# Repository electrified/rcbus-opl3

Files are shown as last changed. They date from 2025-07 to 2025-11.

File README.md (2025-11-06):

# RCBus OPL3 Sound card

An OPL3 sound card for RC2014/RCBus based computers, based on the Yamaha YMF262 and YAC512 ICs.

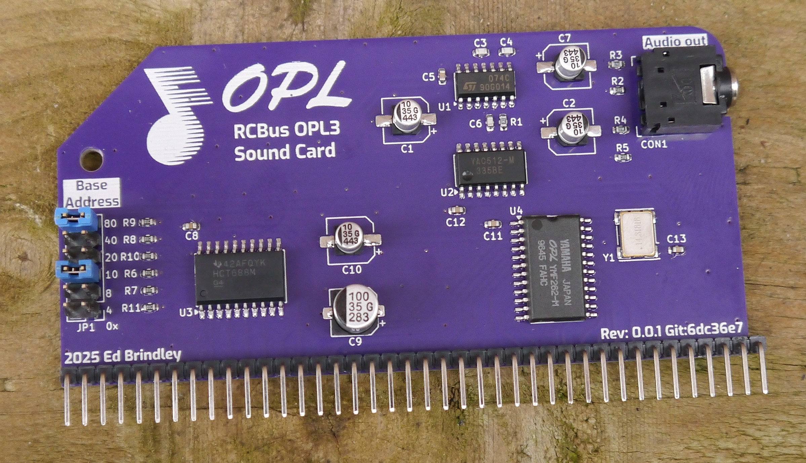
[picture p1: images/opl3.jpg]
Picture of the board


## Building the board
A site built from the sources is available https://electrified.github.io/rcbus-opl3-site. For Gerbers to get your own PCB manufactured see here, download the most appropriate zip for your PCB manufacturer: https://electrified.github.io/rcbus-opl3-site/Browse/rcbus-opl3-navigate_PCB_fabrication_gerber.html

### BOM
The BOM for the board is available here https://electrified.github.io/rcbus-opl3-site/Browse/rcbus-opl3-navigate_Schematic_BoM.html. The CSV version can be loaded into sites that have BOM upload functionality.

## Configuration
The base address the card is available at is configured with JP1 - the default setting which VGMPLAY expects is **0x90** - place jumpers on the 10 and 80 rows to achieve this

## VGM playback
A lightly altered version of Marco Maccaferri and J.B. Langston's CP/M VGMPLAY is available [here](https://github.com/electrified/vgmplay). This allows playback of VGM files containing OPL2 and OPL3 content.

### Sources of OPL2/OPL3 VGM music
[OPL Archive](https://opl.wafflenet.com/#AmigaX)  
OPL3 Archive zip [from this page](https://roudoudou.com/ACE-DL/) - files are names in 8.3 format  
[VGMRips OPL2](https://vgmrips.net/packs/chip/ym3812)  
[VGMRips OPL3](https://vgmrips.net/packs/chip/ymf262)  
[VGMRips full download packs](https://vgmrips.net/forum/viewtopic.php?t=496)  

## Known issues with rev 1
* YMF footprint too narrow
* 10uf cap footprints too large
* Pin 1 not indicated for oscillator
* Noise on startup before reset?
* Cutout for line out isn't quite deep enough for the jack to sit flush without removing a bit of the plastic

## Sponsorship
The first run of prototype PCBs was kindly provided by [PCBWay](https://www.pcbway.com/)! This was the first time I used their service, and I have been impressed with the process and the quality of the boards. I opted for purple boards with a HASL finish - the soldermask is quite opaque, it's a nice finish though and the quality of the boards is high. They also managed to put their serial number / identifier under an IC footprint so it's nicely concealed which not all the board houses manage!

A stencil was ordered to go along with the PCB to allow solder paste to be used and to do reflow soldering on a hotplate - this worked well. 

I opted for the cheapest post option, and it was still pretty speedy to the UK, I'm not sure I'd bother paying for one of the more expensive options unless I was really in a rush.

## License
RCBus OPL3 Sound Card ©2025 by Ed Brindley is licensed under CC BY-SA 4.0. To view a copy of this license, visit https://creativecommons.org/licenses/by-sa/4.0/

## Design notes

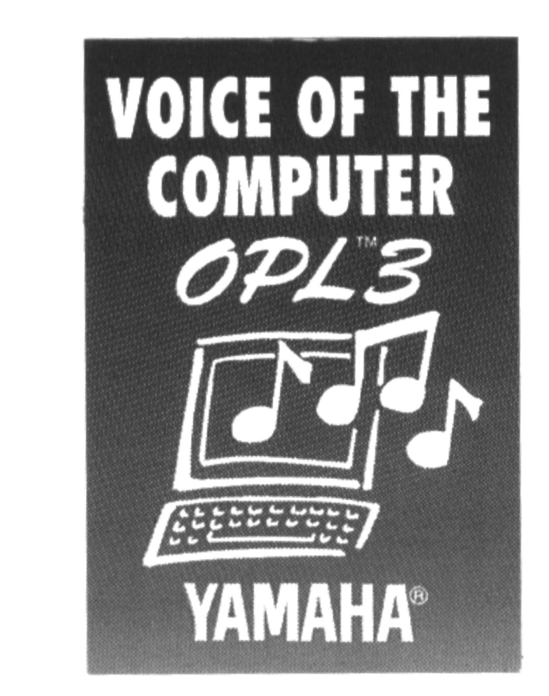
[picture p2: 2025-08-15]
images/Screenshot_20250808_092617.png

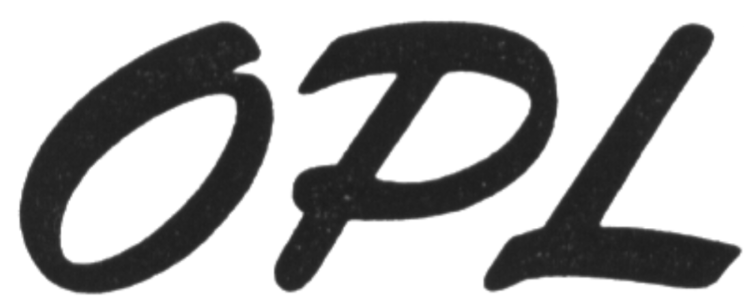
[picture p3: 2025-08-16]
images/opl.png

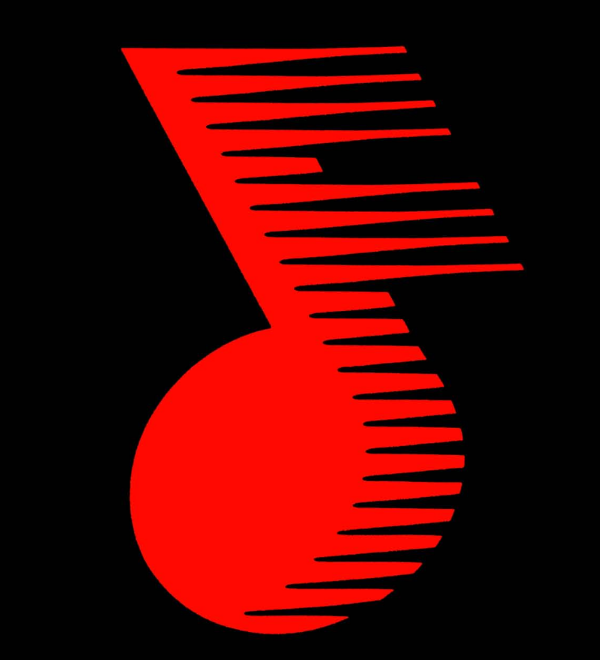
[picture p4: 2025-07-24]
images/adlib.png

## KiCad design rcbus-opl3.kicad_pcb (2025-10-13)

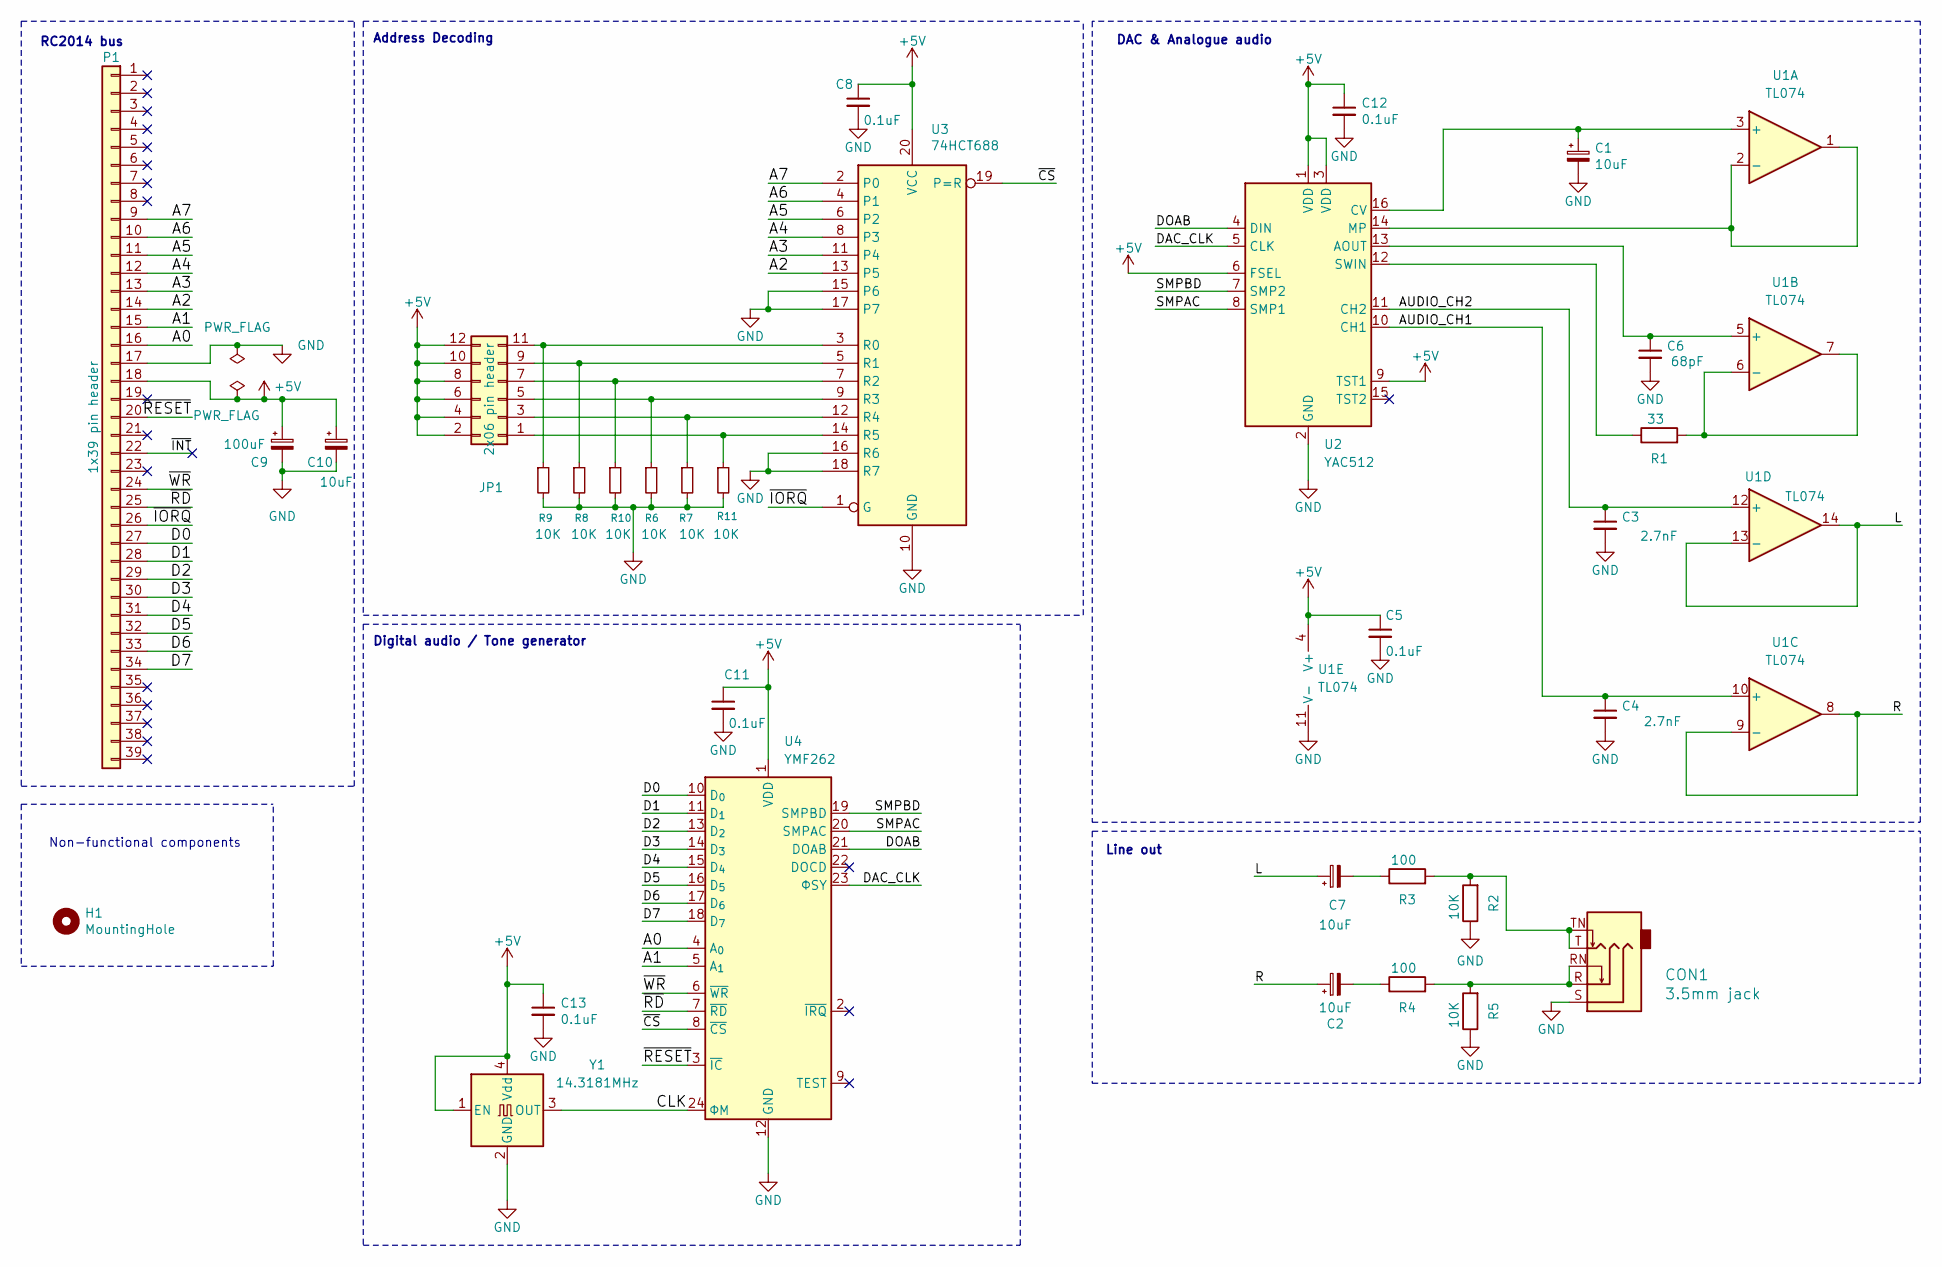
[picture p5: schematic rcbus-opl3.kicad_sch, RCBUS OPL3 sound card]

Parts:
C1, C2, C7, C10: 10uF; CP_Elec_6.3x5.8; MPN EDK106M035A9BAA
C3, C4: 2.7nF; C_0603_1608Metric; MPN MC0603N272J500CT
C5, C8, C11, C12, C13: 0.1uF; C_0603_1608Metric; MPN MC0603B104M250CT
C6: 68pF; C_0603_1608Metric; MPN MC0603N680J500CT
C9: 100uF; CP_Elec_6.3x7.7; MPN EDK107M035A9HAA
CON1: 3.5mm jack; Headphone_Jack_3.5mm_5_pin; MPN FC68131
H1: MountingHole; MountingHole_3.2mm_M3
JP1: 2x06 pin header; PinHeader_2x06_P2.54mm_Vertical; MPN M20-9980346
P1: 1x39 pin header; PinHeader_1x39_P2.54mm_Vertical; MPN 61304011021
R1: 33; R_0603_1608Metric; MPN MCWR06X33R0FTL
R2, R5, R6, R7, R8, R9, R10, R11: 10K; R_0603_1608Metric; MPN MCWR06X1002FTL
R3, R4: 100; R_0603_1608Metric; MPN MCWR06X1000FTL
U1: TL074; SOIC-14_3.9x8.7mm_P1.27mm; MPN TL074CDT
U2: YAC512; SOP-16_4.55x10.3mm_P1.27mm
U3: 74HCT688; SOIC-20W_7.5x12.8mm_P1.27mm; MPN CD74HCT688M96
U4: YMF262; SOP-24_7.5x15.4mm_P1.27mm
Y1: 14.3181MHz; Oscillator_SMD_Abracon_ASV-4Pin_7.0x5.1mm; MPN MCSJK-6NC1-14.31818-25-B

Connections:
+5V: C5.1, C8.1, C9.1, C10.1, C11.1, C12.1, C13.1, JP1.2, JP1.4, JP1.6, JP1.8, JP1.10, JP1.12, P1.18, U1.4 (V+), U2.1 (VDD), U2.3 (VDD), U2.6 (FSEL), U2.9 (TST1), U3.20 (VCC), U4.1 (VDD), Y1.1 (EN), Y1.4 (Vdd)
/A0: P1.16, U4.4 (A_{0})
/A1: P1.15, U4.5 (A_{1})
/A2: P1.14, U3.13 (P5)
/A3: P1.13, U3.11 (P4)
/A4: P1.12, U3.8 (P3)
/A5: P1.11, U3.6 (P2)
/A6: P1.10, U3.4 (P1)
/A7: P1.9, U3.2 (P0)
/AUDIO_CH1: C4.1, U1.10 (+), U2.10 (CH1)
/AUDIO_CH2: C3.1, U1.12 (+), U2.11 (CH2)
/CLK: U4.24 (ΦM), Y1.3 (OUT)
/D0: P1.27, U4.10 (D_{0})
/D1: P1.28, U4.11 (D_{1})
/D2: P1.29, U4.13 (D_{2})
/D3: P1.30, U4.14 (D_{3})
/D4: P1.31, U4.15 (D_{4})
/D5: P1.32, U4.16 (D_{5})
/D6: P1.33, U4.17 (D_{6})
/D7: P1.34, U4.18 (D_{7})
/DAC_CLK: U2.5 (CLK), U4.23 (ΦSY)
/DOAB: U2.4 (DIN), U4.21 (DOAB)
/L: C7.1, U1.13 (-), U1.14
/R: C2.1, U1.8, U1.9 (-)
/SMPAC: U2.8 (SMP1), U4.20 (SMPAC)
/SMPBD: U2.7 (SMP2), U4.19 (SMPBD)
/~CS: U3.19 (P=R), U4.8 (~CS)
/~INT: P1.22
/~IORQ: P1.26, U3.1 (G)
/~RD: P1.25, U4.7 (~RD)
/~RESET: P1.20, U4.3 (~IC)
/~WR: P1.24, U4.6 (~WR)
GND: C1.2, C3.2, C4.2, C5.2, C6.2, C8.2, C9.2, C10.2, C11.2, C12.2, C13.2, CON1.S, P1.17, R2.1, R5.1, R6.2, R7.2, R8.2, R9.2, R10.2, R11.2, U1.11 (V-), U2.2 (GND), U3.10 (GND), U3.15 (P6), U3.16 (R6), U3.17 (P7), U3.18 (R7), U4.12 (GND), Y1.2 (GND)
unnamed: C2.2, R4.1
unnamed: C7.2, R3.1
unnamed: CON1.R, CON1.RN, R4.2, R5.2
unnamed: CON1.T, CON1.TN, R2.2, R3.2
unnamed: JP1.1, R11.1, U3.14 (R5)
unnamed: JP1.3, R7.1, U3.12 (R4)
unnamed: JP1.5, R6.1, U3.9 (R3)
unnamed: JP1.7, R10.1, U3.7 (R2)
unnamed: JP1.9, R8.1, U3.5 (R1)
unnamed: JP1.11, R9.1, U3.3 (R0)
unnamed: C1.1, U1.3 (+), U2.16 (CV)
unnamed: U1.1, U1.2 (-), U2.14 (MP)
unnamed: C6.1, U1.5 (+), U2.13 (AOUT)
unnamed: R1.2, U1.6 (-), U1.7
unnamed: R1.1, U2.12 (SWIN)

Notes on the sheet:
Non-functional components
Line out
Digital audio / Tone generator
Address Decoding
DAC & Analogue audio
RC2014 bus

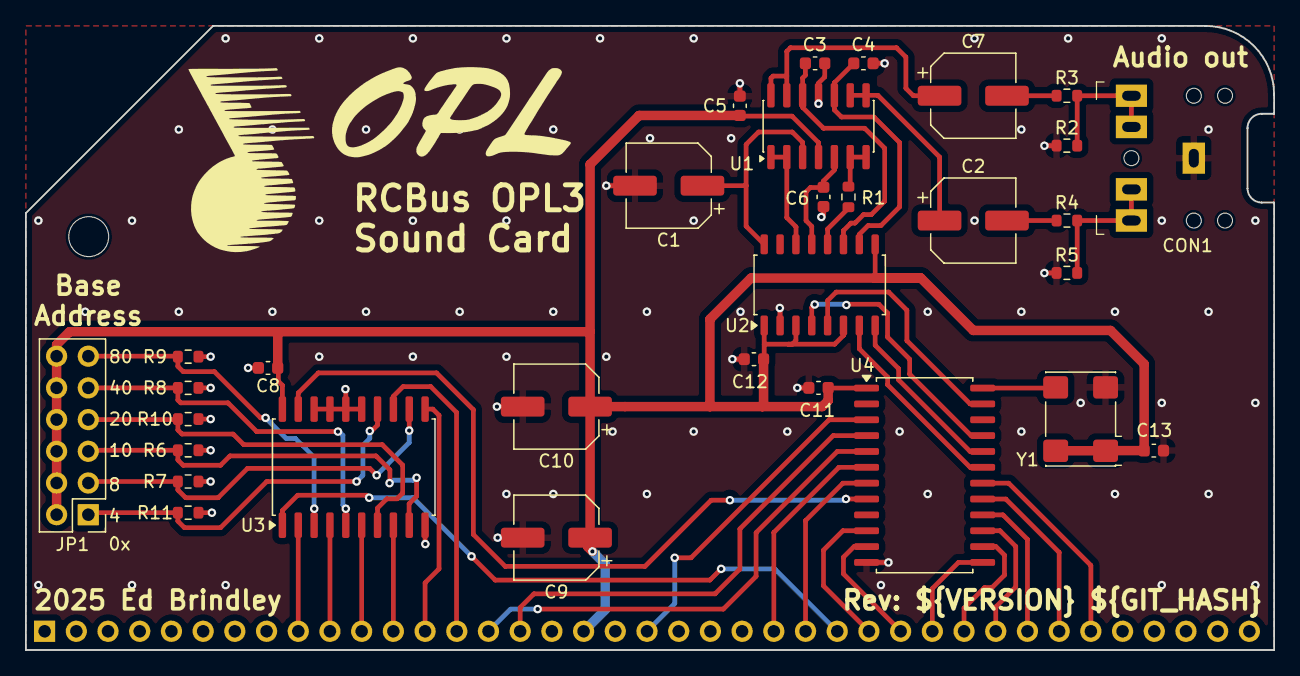
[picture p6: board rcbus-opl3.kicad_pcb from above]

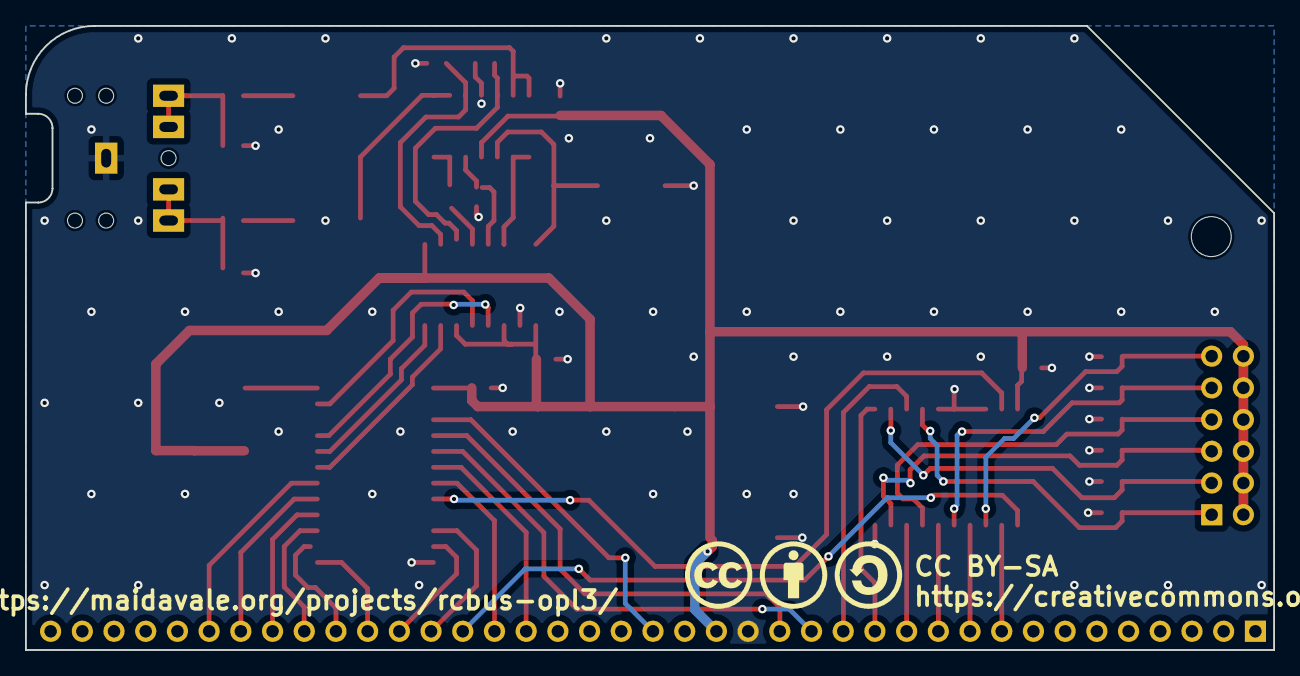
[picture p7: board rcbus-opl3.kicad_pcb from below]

Board: 2 copper layers, 100.0 x 50.0 mm, 38 parts (3 on the bottom side), 47 nets.

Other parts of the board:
G1: LOGO; adlib2
G2: LOGO; opl
G3: Symbol_CreativeCommons_Silk_Type2_Small
G4: Symbol_CC-Attribution_Silk_Small
G5: Symbol_CC-ShareAlike_Silk_Small

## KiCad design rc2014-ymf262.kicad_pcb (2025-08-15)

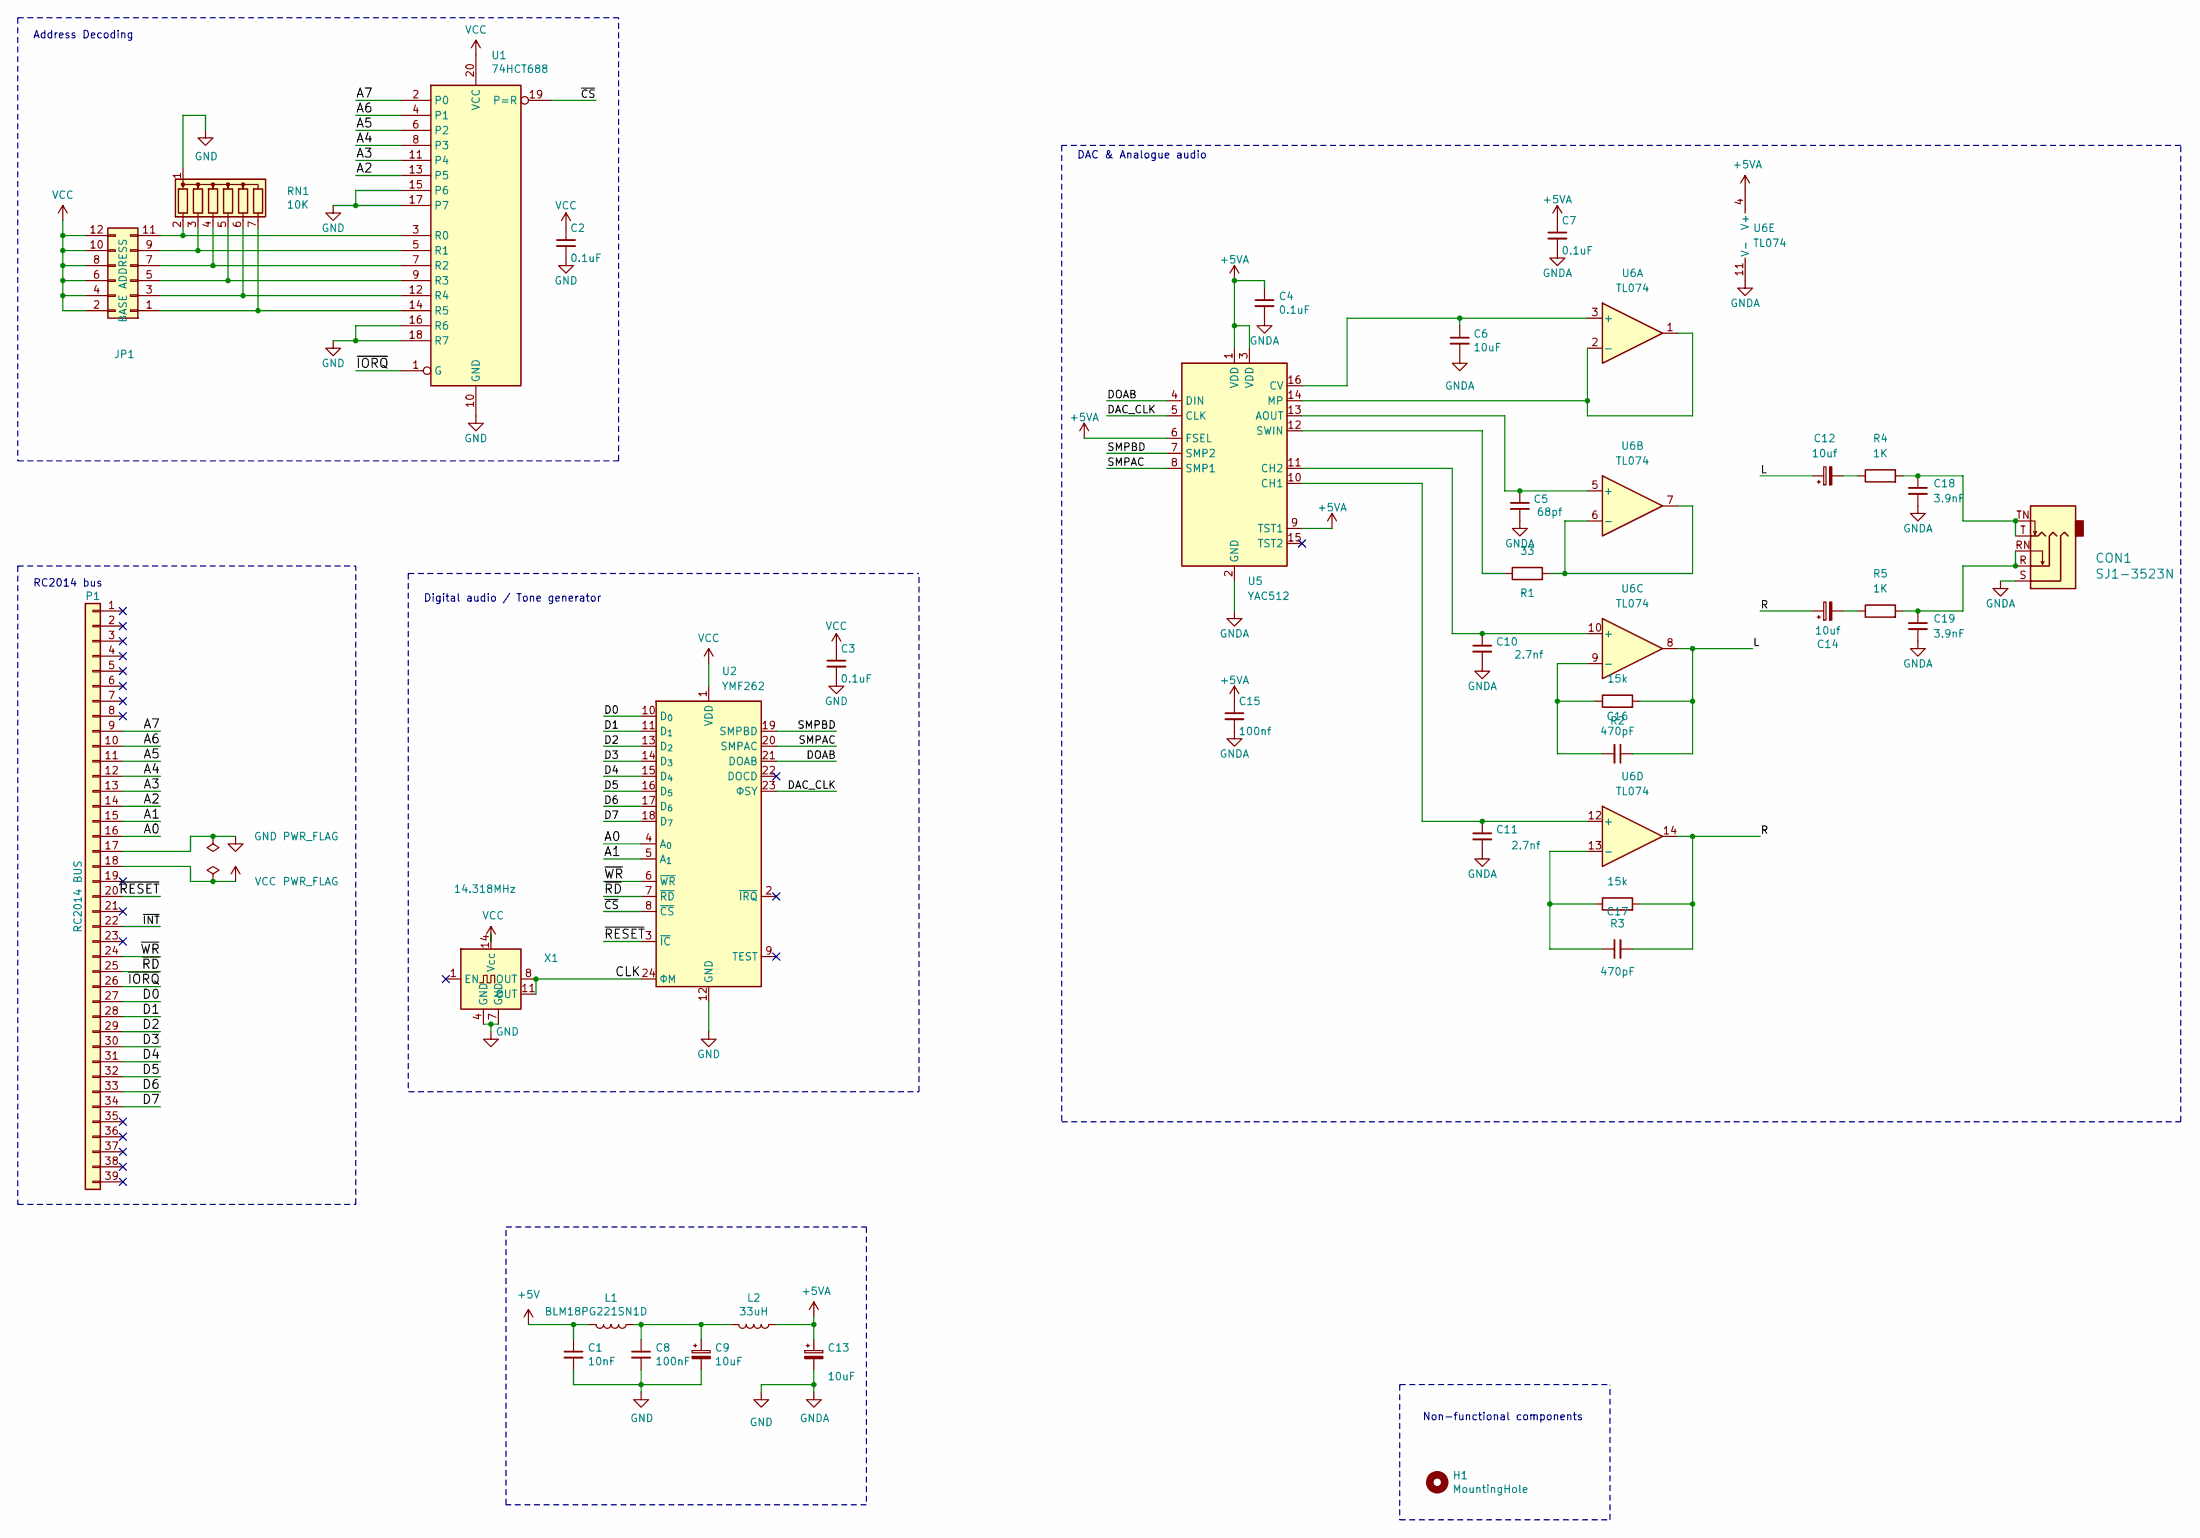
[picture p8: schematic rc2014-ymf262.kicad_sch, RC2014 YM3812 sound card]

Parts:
C1: 10nF; C_0603_1608Metric_Pad1.08x0.95mm_HandSolder
C2, C3, C4, C7: 0.1uF; C_0603_1608Metric_Pad1.08x0.95mm_HandSolder
C5: 68pf; C_0603_1608Metric_Pad1.08x0.95mm_HandSolder
C6: 10uF; C_0603_1608Metric_Pad1.08x0.95mm_HandSolder
C8: 100nF; C_0603_1608Metric_Pad1.08x0.95mm_HandSolder
C9, C13: 10uF; C_1206_3216Metric
C10, C11: 2.7nf; C_0603_1608Metric_Pad1.08x0.95mm_HandSolder
C12, C14: 10uf; C_0603_1608Metric_Pad1.08x0.95mm_HandSolder
C15: 100nf; C_0603_1608Metric_Pad1.08x0.95mm_HandSolder
C16, C17: 470pF; C_0603_1608Metric_Pad1.08x0.95mm_HandSolder
C18, C19: 3.9nF; C_0603_1608Metric_Pad1.08x0.95mm_HandSolder
CON1: SJ1-3523N; Headphone_Jack_3.5mm_5_pin; MPN SJ1-3523N; Digi-Key_PN CP1-3523N-ND
H1: MountingHole; MountingHole_3.2mm_M3
JP1: BASE ADDRESS; PinHeader_2x06_P2.54mm_Vertical
L1: BLM18PG221SN1D; L_0603_1608Metric_Pad1.05x0.95mm_HandSolder
L2: 33uH; L_0603_1608Metric_Pad1.05x0.95mm_HandSolder
P1: RC2014 BUS; PinHeader_1x39_P2.54mm_Vertical
R1: 33; R_0603_1608Metric_Pad0.98x0.95mm_HandSolder
R2, R3: 15k; R_0603_1608Metric_Pad0.98x0.95mm_HandSolder
R4, R5: 1K; R_0603_1608Metric_Pad0.98x0.95mm_HandSolder
RN1: 10K; R_Array_Convex_8x0602
U1: 74HCT688; SOIC-20W_7.5x12.8mm_P1.27mm
U2: YMF262; SOP-24_7.5x15.4mm_P1.27mm
U5: YAC512; SOP-16_4.55x10.3mm_P1.27mm
U6: TL074; SOIC-14_3.9x8.7mm_P1.27mm
X1: 14.318MHz; Oscillator_DIP-8-14

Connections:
+5V: C1.1, L1.2
+5VA: C4.1, C7.1, C13.1, C15.1, L2.1, U5.1 (VDD), U5.3 (VDD), U5.6 (FSEL), U5.9 (TST1), U6.4 (V+)
/A0: P1.16, U2.4 (A_{0})
/A1: P1.15, U2.5 (A_{1})
/A2: P1.14, U1.13 (P5)
/A3: P1.13, U1.11 (P4)
/A4: P1.12, U1.8 (P3)
/A5: P1.11, U1.6 (P2)
/A6: P1.10, U1.4 (P1)
/A7: P1.9, U1.2 (P0)
/CLK: U2.24 (ΦM), X1.8 (OUT), X1.11 (OUT)
/D0: P1.27, U2.10 (D_{0})
/D1: P1.28, U2.11 (D_{1})
/D2: P1.29, U2.13 (D_{2})
/D3: P1.30, U2.14 (D_{3})
/D4: P1.31, U2.15 (D_{4})
/D5: P1.32, U2.16 (D_{5})
/D6: P1.33, U2.17 (D_{6})
/D7: P1.34, U2.18 (D_{7})
/DAC_CLK: U2.23 (ΦSY), U5.5 (CLK)
/DOAB: U2.21 (DOAB), U5.4 (DIN)
/L: C12.1, C16.1, R2.2, U6.8
/R: C14.1, C17.2, R3.2, U6.14
/SMPAC: U2.20 (SMPAC), U5.8 (SMP1)
/SMPBD: U2.19 (SMPBD), U5.7 (SMP2)
/~CS: U1.19 (P=R), U2.8 (~CS)
/~INT: P1.22
/~IORQ: P1.26, U1.1 (G)
/~RD: P1.25, U2.7 (~RD)
/~RESET: P1.20, U2.3 (~IC)
/~WR: P1.24, U2.6 (~WR)
GND: C1.2, C2.2, C3.2, C4.2, C5.2, C6.2, C7.2, C8.2, C9.2, C10.2, C11.2, C13.2, C15.2, C18.2, C19.2, CON1.S, P1.17, RN1.1 (common), U1.10 (GND), U1.15 (P6), U1.16 (R6), U1.17 (P7), U1.18 (R7), U2.12 (GND), U5.2 (GND), U6.11 (V-), X1.4 (GND), X1.7 (GND)
unnamed: C8.1, C9.1, L1.1, L2.2
unnamed: C12.2, R4.1
unnamed: C14.2, R5.1
unnamed: C18.1, CON1.T, CON1.TN, R4.2
unnamed: C19.1, CON1.R, CON1.RN, R5.2
unnamed: JP1.1, RN1.7 (R6), U1.14 (R5)
unnamed: JP1.3, RN1.6 (R5), U1.12 (R4)
unnamed: JP1.5, RN1.5 (R4), U1.9 (R3)
unnamed: JP1.7, RN1.4 (R3), U1.7 (R2)
unnamed: JP1.9, RN1.3 (R2), U1.5 (R1)
unnamed: JP1.11, RN1.2 (R1), U1.3 (R0)
unnamed: C5.1, U5.13 (AOUT), U6.5 (+)
unnamed: C11.1, U5.10 (CH1), U6.12 (+)
unnamed: C10.1, U5.11 (CH2), U6.10 (+)
unnamed: C6.1, U5.16 (CV), U6.3 (+)
unnamed: U5.14 (MP), U6.1, U6.2 (-)
unnamed: R1.1, U5.12 (SWIN)
unnamed: R1.2, U6.6 (-), U6.7
unnamed: C16.2, R2.1, U6.9 (-)
unnamed: C17.1, R3.1, U6.13 (-)
VCC: C2.1, C3.1, JP1.2, JP1.4, JP1.6, JP1.8, JP1.10, JP1.12, P1.18, U1.20 (VCC), U2.1 (VDD), X1.14 (Vcc)

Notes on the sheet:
Non-functional components
Digital audio / Tone generator
Address Decoding
DAC & Analogue audio
RC2014 bus

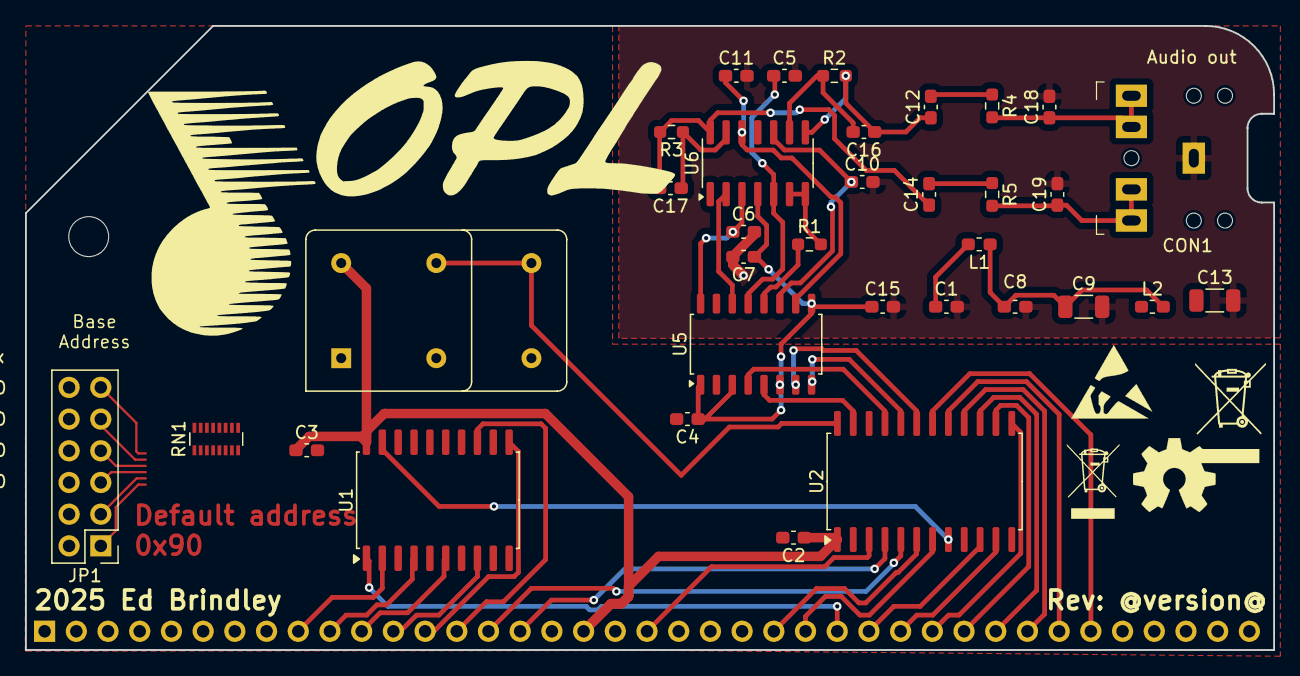
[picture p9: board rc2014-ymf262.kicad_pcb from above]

Board: 2 copper layers, 100.0 x 50.0 mm, 38 parts (0 on the bottom side), 52 nets.

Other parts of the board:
G1: LOGO; adlib
G2: LOGO; opl

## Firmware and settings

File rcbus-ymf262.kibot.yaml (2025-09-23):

# This is a working example.
# For a more complete reference use `--example`
kibot:
  version: 1

global:
  filters:
  - number: 1007
  - number: 1015
  - number: 58
  - number: 107

import:
- file: JLCPCB
  definitions:
    _KIBOT_MANF_DIR: Manufacturers/JLCPCB
    _KIBOT_POS_PRE_TRANSFORM: '[''_kicost_rename'', ''_rot_footprint'']'
    _KIBOT_BOM_ENABLED: 'false'
- file: PCB2Blender_2_1
- file: PCBWay
  definitions:
    _KIBOT_MANF_DIR: Manufacturers/PCBWay

preflight:
  drc:
    dont_stop: true
    format: HTML,RPT,JSON,CSV
  erc:
    dont_stop: true
    format: HTML,RPT,JSON,CSV
  set_text_variables:
    # The revision will be the short git hash
    # We use ${git_hash} for the REV field in the worksheet (frame)
    - name: 'GIT_HASH'
      command: 'git log -1 --format="%h" $KIBOT_PCB_NAME'
      before: 'Git:'
    # Coherent date and time for the schematic and PCB
    # This will be the time stamp of the files generation, not the commit times
    # We use `${date}` for the time field in the worksheet (frame)
    - name: 'DATE'
      command: 'date --iso-8601=minutes'
    - name: 'VERSION'
      command: 'echo $VERSION'

outputs:
- name: basic_blender_export
  comment: 3D view from top/30 deg/bottom (Blender)
  type: blender_export
  dir: 3D
  options:
    pcb3d: _PCB2Blender_2_1
    outputs:
    - type: render
    - type: blender
    point_of_view:
    - view: top
    - rotate_x: 30
      rotate_z: -20
      file_id: _30deg
    - view: bottom
- name: generic_bom_html
  comment: Generic Bill of Materials in HTML format
  type: bom
  dir: BoM/Generic
  options:
    format: HTML
    group_fields: &id001
    - part
    - part lib
    - value
    - footprint
    - footprint lib
    - voltage
    - tolerance
    - current
    - power
    - mpn
    count_smd_tht: true
- name: generic_bom_csv
  comment: Generic Bill of Materials in CSV format
  type: bom
  dir: BoM/Generic
  options:
    format: CSV
    group_fields: *id001
    count_smd_tht: true
- name: generic_bom_xlsx
  comment: Generic Bill of Materials in XLSX format
  type: bom
  dir: BoM/Generic
  options:
    format: XLSX
    group_fields: *id001
    count_smd_tht: true
- name: positional_bom_html
  comment: Positional Bill of Materials in HTML format
  type: bom
  dir: BoM/Positional
  options:
    format: HTML
    group_fields: *id001
    columns: &id002
    - Row
    - Description
    - Part
    - Part Lib
    - References
    - Value
    - Footprint
    - Footprint Lib
    - Quantity Per PCB
    - Build Quantity
    - Status
    - Datasheet
    - Sheetpath
    - Source BoM
    - ${DNP}
    - ${EXCLUDE_FROM_BOARD}
    - ${EXCLUDE_FROM_SIM}
    - footprint full
    - Footprint X
    - Footprint Y
    - Footprint Rot
    - Footprint Side
    - Footprint Type
    - Footprint Type NV
    - Footprint Populate
    - Footprint X-Size
    - Footprint Y-Size
    - ${ITEM_NUMBER}
    - Net Name
    - Net Label
    - Net Class
    - ${QUANTITY}
    count_smd_tht: true
    html:
      style: modern-red
- name: positional_bom_xlsx
  comment: Positional Bill of Materials in XLSX format
  type: bom
  dir: BoM/Positional
  options:
    format: XLSX
    group_fields: *id001
    columns: *id002
    count_smd_tht: true
    xlsx:
      style: modern-red
- name: costs_bom_xlsx
  comment: Costs Bill of Materials in XLSX format
  type: bom
  dir: BoM/Costs
  options:
    format: XLSX
    group_fields:
    - part
    - part lib
    - value
    - footprint
    - footprint lib
    - voltage
    - tolerance
    - current
    - power
    - manf#
    count_smd_tht: true
    xlsx:
      style: modern-green
      kicost: true
      specs: true
      kicost_api_disable: KitSpace
    pre_transform: _kicost_rename
- name: kicad_internal_bom
  type: bom
  dir: BoM/KiCad
  comment: BoM using KiCad settings
  options:
    format: KICAD
    ignore_dnf: false
    group_not_fitted: true
    group_fields: []
    sort_style: kicad_bom
    columns:
    - _kicad_bom_fields
- name: basic_diff_pcb
  comment: PCB diff between the last two changes
  type: diff
  dir: diff
  layers:
  - layer: Front
    suffix: Front
    description: No description
  - layer: F.Mask
    suffix: F_Mask
    description: Front soldermask (negative)
  - layer: Back
    suffix: Back
    description: No description
  - layer: B.Mask
    suffix: B_Mask
    description: Bottom soldermask (negative)
  - layer: F.Silkscreen
    suffix: F_Silkscreen
    description: Front silkscreen (artwork)
  - layer: B.Silkscreen
    suffix: B_Silkscreen
    description: Bottom silkscreen (artwork)
  - layer: F.Paste
    suffix: F_Paste
    description: Front solder paste
  - layer: User.Drawings
    suffix: User_Drawings
    description: User drawings
  - layer: User.Comments
    suffix: User_Comments
    description: User comments
  - layer: Edge.Cuts
    suffix: Edge_Cuts
    description: Board shape
  - layer: F.Courtyard
    suffix: F_Courtyard
    description: Front courtyard area
  - layer: F.Fab
    suffix: F_Fab
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

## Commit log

2025-07-22 initial commit
    wip
    [rc2014-ymf262.kicad_pcb, rc2014-ymf262.kicad_sch]
2025-07-22 initial work on schematic
    [rc2014-ymf262.kicad_sch]
2025-07-23 move to use mostly SMD
    [rc2014-ymf262.kicad_pcb, rc2014-ymf262.kicad_sch]
2025-07-24 use custom oscillator footprint
    [rc2014-ymf262.kicad_pcb, rc2014-ymf262.kicad_sch]
2025-08-04 more work on schematic and layout
    [rc2014-ymf262.kicad_pcb, rc2014-ymf262.kicad_sch]
2025-08-15 add additional docs and other random updates
    [rc2014-ymf262.kicad_pcb, rc2014-ymf262.kicad_sch]
2025-08-16 some more routing, use individual resistors, change name to rcbus
    [rcbus-ymf262.kicad_pcb, rcbus-ymf262.kicad_sch]
2025-08-17 fully routed - first attempt
    [rcbus-ymf262.kicad_pcb]
2025-08-17 move some vias out of pads
    [rcbus-ymf262.kicad_pcb]
2025-08-19 more routing
    [rcbus-ymf262.kicad_pcb, rcbus-ymf262.kicad_sch]
2025-08-20 pcb updates, remove old github actions
    [rcbus-ymf262.kicad_pcb, rcbus-ymf262.kicad_sch]
2025-08-21 use updated footprints, update library submodule
    [rcbus-ymf262.kicad_pcb]
2025-08-26 use smd oscillator
    [rcbus-ymf262.kicad_pcb, rcbus-ymf262.kicad_sch]
2025-08-28 set version no
    [rcbus-ymf262.kicad_pcb, rcbus-ymf262.kicad_sch]
2025-08-28 more versioning stuff
    [rcbus-ymf262.kicad_pcb, rcbus-ymf262.kicad_sch]
2025-08-31 remove gnda, another attempt at versioning
    [rcbus-ymf262.kicad_pcb, rcbus-ymf262.kicad_sch]
2025-09-01 more kibot work
    [rcbus-ymf262.kicad_pcb]
2025-09-02 replace with quick start config
    [rcbus-ymf262.kibot.yaml]
2025-09-11 some pcb tidyup, use netcallses for track widths
    [rcbus-ymf262.kicad_pcb]
2025-09-12 update logo
    [rcbus-ymf262.kicad_pcb]
2025-09-20 update url
    [rcbus-ymf262.kicad_pcb]
2025-09-20 further silkscreen tidyups
    [rcbus-ymf262.kicad_pcb]
2025-09-21 remove some components, more tidyup
    [rcbus-ymf262.kicad_pcb, rcbus-ymf262.kicad_sch]
2025-09-23 rename to rcbus-opl3
    [rcbus-opl3.kicad_pcb, rcbus-opl3.kicad_sch]
2025-09-23 try and fix diff
    [rcbus-ymf262.kibot.yaml]
2025-09-24 remove unneeded components, some layour rejigging
    [rcbus-opl3.kicad_pcb, rcbus-opl3.kicad_sch]
2025-09-26 add additional output caps/ resistors
    [rcbus-opl3.kicad_pcb, rcbus-opl3.kicad_sch]
2025-10-01 remove some unusted stuff from kibot, update schematic and pcb
    [rcbus-opl3.kicad_pcb, rcbus-opl3.kicad_sch]
2025-10-02 as submitted for design review on reddit
    [rcbus-opl3.kicad_pcb]
2025-10-04 use gitignore from https://github.com/github/gitignore/blob/main/KiCad.gitignore
2025-10-04 reroute. add additional bulk cap
    [rcbus-opl3.kicad_pcb, rcbus-opl3.kicad_sch]
2025-10-05 rotate u2
    [rcbus-opl3.kicad_pcb]
2025-10-06 increase spacing between tracks, remove opl4 pdf
    [rcbus-opl3.kicad_pcb]
2025-10-07 remove 5v pour
    [rcbus-opl3.kicad_pcb]
2025-10-08 add cc logos and some tidyup
    [rcbus-opl3.kicad_pcb]
2025-10-09 add stitching vias
    [rcbus-opl3.kicad_pcb, rcbus-opl3.kicad_sch]
2025-10-09 more tidyup
    [rcbus-opl3.kicad_pcb, rcbus-opl3.kicad_sch]
2025-10-09 tidy up text
    [rcbus-opl3.kicad_pcb]
2025-10-10 sync up pcb and schematic, minor schematic tidyups
    [rcbus-opl3.kicad_pcb, rcbus-opl3.kicad_sch]
2025-10-11 update some part fields
    [rcbus-opl3.kicad_pcb]
2025-10-12 add datasheets / farnell links
    [rcbus-opl3.kicad_pcb, rcbus-opl3.kicad_sch]
2025-10-12 update the parts for the large caps
    [rcbus-opl3.kicad_sch]
2025-10-13 add mpn field
    [rcbus-opl3.kicad_pcb, rcbus-opl3.kicad_sch]
